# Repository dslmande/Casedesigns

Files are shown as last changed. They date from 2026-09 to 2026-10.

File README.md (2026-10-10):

# Case designs

Mechanical designs (front panels, rear panels, enclosures) for DIY synthesizer and
effects projects — parametric, generated from Python scripts, with ready-to-order
manufacturing files.

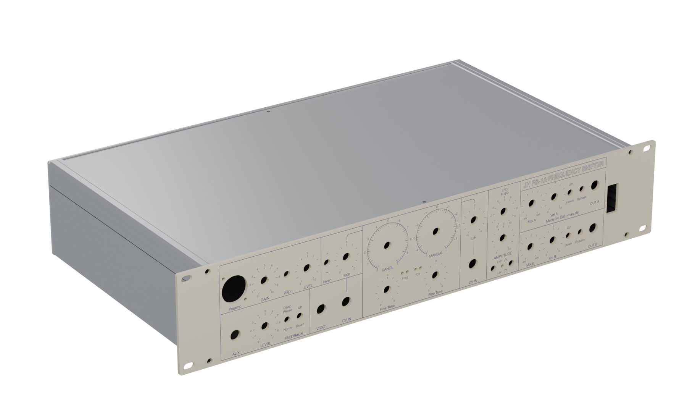
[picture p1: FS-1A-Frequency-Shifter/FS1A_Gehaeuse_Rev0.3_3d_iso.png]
FS-1A enclosure


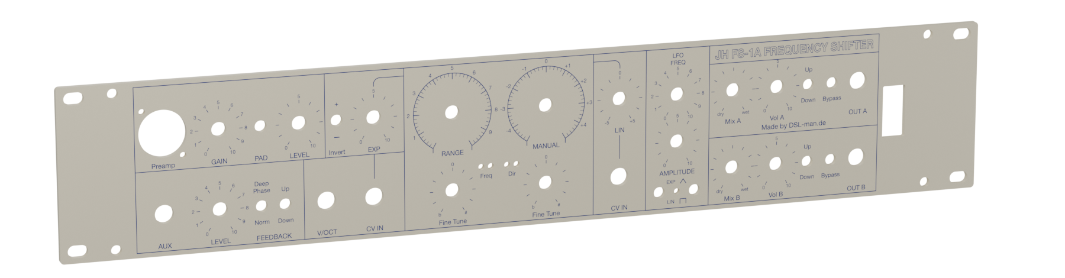
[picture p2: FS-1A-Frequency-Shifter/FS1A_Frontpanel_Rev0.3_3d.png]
FS-1A front panel


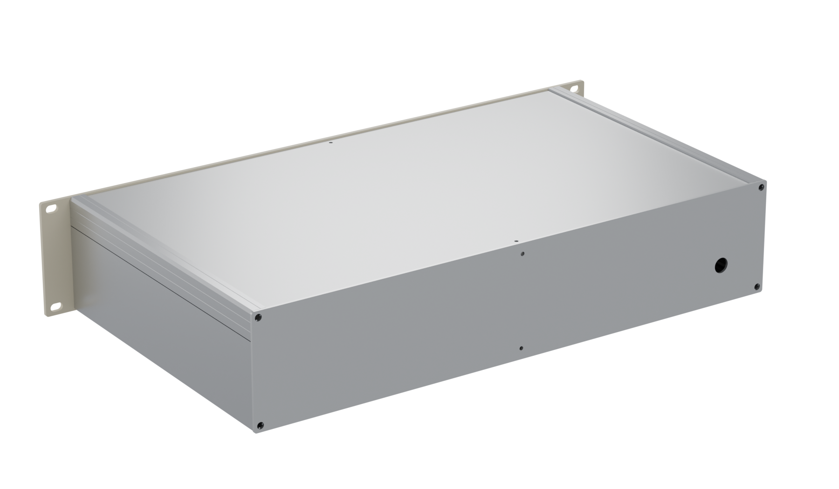
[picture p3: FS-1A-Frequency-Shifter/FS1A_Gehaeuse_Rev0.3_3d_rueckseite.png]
FS-1A rear


*FS-1A Frequency Shifter: 19" / 2 U enclosure, front panel with the full-surface
colour print, and the rear. Rendered from the STEP assembly these files produce —
the panel carries the actual print artwork, not a mock-up.*

**[Turn it around in your browser](https://dslmande.github.io/fs1a-case-3d/)** — an
interactive 3D view of the enclosure and the control PCBs.

| Design | Description |
|---|---|
| [FS-1A Frequency Shifter](FS-1A-Frequency-Shifter/) | 19" / 2 U front panel, rear panel and enclosure for Jürgen Haible's FS-1A frequency shifter |

Every design folder contains the generator scripts, the production files (Schaeffer
`.fpd`, DXF, print-ready PDF), a 3D assembly as STEP, and its own README.

## Control panel PCBs

For the FS-1A there is a set of control panel PCBs that carries the pots, switches,
jacks and LEDs behind the front panel, so the build needs no point-to-point wiring.
Three boards, one per block of the panel layout, wired to each other with a single
6-way link and to Haible's boards with the connectors he already uses.

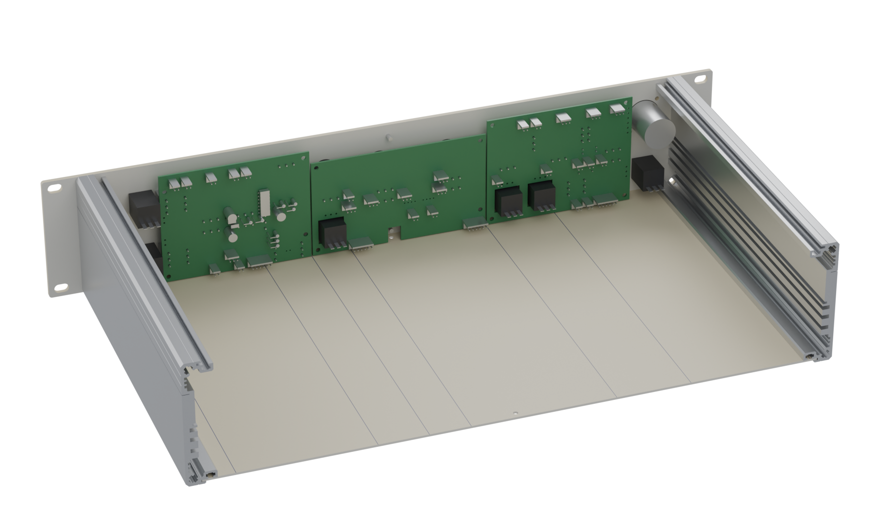
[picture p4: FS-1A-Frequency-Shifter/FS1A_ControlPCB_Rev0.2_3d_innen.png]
Control panel PCBs behind the front panel


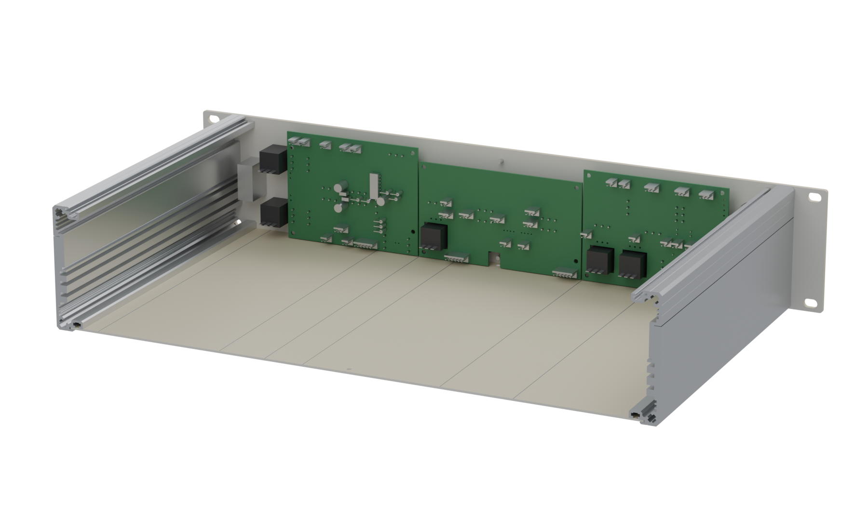
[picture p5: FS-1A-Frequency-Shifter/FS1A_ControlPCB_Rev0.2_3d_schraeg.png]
Control panel PCBs from the side


Those boards are not part of this repository — they are **available on request from
[diysynth.de](https://diysynth.de)**.

## License

© 2026 Dsl-man.de

Licensed under [Creative Commons Attribution-ShareAlike 4.0 International](LICENSE)
(CC BY-SA 4.0) — including the generator scripts. You may build, modify and redistribute
these designs, commercially too, as long as you credit the source and share your changes
under the same license.

Third-party data included for reference keeps its own origin: the side-rail cross-section
comes from Gie-Tec's published CAD file, `rowmans.jhf` is the public-domain Hershey font.

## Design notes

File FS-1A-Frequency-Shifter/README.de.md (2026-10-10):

# Frontpanel – Jürgen Haible Frequency Shifter FS-1A (19", 2 HE)

Gestaltung nach dem Vorbild des Van-Daal-Aufbaus (cremefarbene Blende,
dunkelblauer Druck, Funktionsblöcke mit Rahmenlinien, große RANGE/MANUAL-Knöpfe).

## Versionsstand

Alle erzeugten Dateien tragen den Stand im Namen, Schema
`FS1A_<Teil>_Rev<x.y>[_<Zusatz>].<ext>` – aktuell **Rev0.3**. Die Generatoren
(`fs1a_panel.py`, `fs1a_rueckwand.py`, `fs1a_gehaeuse.py`, `fs1a_step.py`) und die
Eingangsdaten (`gietec_122040_profil.dat`, `rowmans.jhf`) bleiben ohne Version, sie
sind das Werkzeug. Der Stand steht an einer Stelle: `REV` am Anfang von
`fs1a_panel.py`; die anderen Skripte übernehmen ihn von dort.

Jede Maß- oder Bauteiländerung an einem Teil ist ein neuer Stand: `REV` hochzählen,
alles neu erzeugen, die alten Dateien behalten oder verwerfen – so kommen bestellte
Platten und Daten nicht durcheinander.

> **Die Druckvariante speichert das Skript nicht.** „Weiß drucken“ und „Weiß
> unterdrucken“ gibt es nur im Eigenschaften-Dialog, eine vom Skript geschriebene
> Datei hätte sie immer auf Nein. Also: Skript laufen lassen, beide setzen, dann von
> Hand als `FS1A_Frontpanel_Rev0.3_druck.fpd` sichern.

## Dateien

| Datei | Inhalt |
|---|---|
| `fs1a_panel.py` | Generator (nur Python-Standardbibliothek): `/usr/bin/python3 fs1a_panel.py` schreibt alle Ausgabedateien neu |
| `FS1A_Frontpanel_Rev0.3_druck.fpd` | **FrontDesign, Farbdruck-Variante:** eloxiert natur + vollflächige Druckgrafik (Creme + Blau), Bohrungen als Bohrelemente |
| `FS1A_Frontpanel_Rev0.3_druck.pdf` | Die Druckgrafik: Vektor-PDF 1:1, 484,7 × 90,3 mm (1 mm Beschnitt rundum), ohne Bohrungen/Kontur |
| `FS1A_Frontpanel_Rev0.3_druck.fpjs` | FrontDesign-Skript, das die Druck-Variante erzeugt |
| `FS1A_Frontpanel_Rev0.3.fpd` | FrontDesign, Gravur-Variante: Text/Linien als native Elemente (gravieren oder „Gravuren drucken“) |
| `FS1A_Frontpanel_Rev0.3.fpjs` | FrontDesign-Skript für die Gravur-Variante |
| `FS1A_Frontpanel_Rev0.3.dxf` | DXF R12, Ebenen `KONTUR` / `AUSSCHNITTE` / `DRUCK`, Text als Pfade |
| `FS1A_Frontpanel_Rev0.3.svg` | 1:1 in mm mit Inkscape-Ebenen und Bauteil-Vorschau |
| `FS1A_Frontpanel_Rev0.3_druck.svg` | Quelle der Druckgrafik (nur Panelfarbe + Druck) |
| `FS1A_Frontpanel_Rev0.3_bohrungen.csv` | Bohrtabelle: Nr, Bauteil, x (von links), y (von oben), Ø, Bemerkung |
| `FS1A_Frontpanel_Rev0.3_vorschau.png` | Render mit Knöpfen, Buchsen, Schaltern |
| `fs1a_rueckwand.py` | Generator der Rückwand (nutzt `fs1a_panel.py` als Bibliothek) |
| `FS1A_Rueckwand_Rev0.3.fpd` | FrontDesign, Rückwand 437 × 88,1 × 2 mm, Alu eloxiert natur |
| `FS1A_Rueckwand_Rev0.3.svg` / `.dxf` / `.fpjs` / `_bohrungen.csv` / `_vorschau.png` | Rückwand in denselben Formaten |
| `rowmans.jhf` | Hershey-Strichschrift „Roman Simplex“ für den DXF-Text (gemeinfrei) |

Alle Maße und Positionen stehen als Konstanten am Anfang von `fs1a_panel.py`
(Blockgrenzen `X_*`, Reihenhöhen `Y_TOP/Y_BOT`, Bohrdurchmesser `DRILL`, Farben,
Schriftgrößen, `TITLE`, `BRAND`, FrontDesign-Einstellungen `FPD`, Beschnitt `BLEED`).
Die PDF-Erzeugung nutzt Google Chrome headless (`CHROME`-Pfad im Script).

## Farbdruck (UV-Digitaldruck) – `FS1A_Frontpanel_Rev0.3_druck.fpd`

So sieht die Platte aus wie das Vorbild. Regeln aus Schaeffers „Hinweise zur Erstellung
Ihrer Druckdaten“ (Druckdateien.pdf), die der Generator einhält:

- Vektor-PDF, Farben in sRGB (Creme `#F2E7C6`, Blau `#22307C`) – RAL wird nur angenähert.
- Die Druckgrafik läuft rundum ≥ 1 mm über die Plattenkante hinaus (sonst kann unbedruckter Rand sichtbar werden).
- Keine Bohrungen und keine Plattenkontur in der Druckdatei (würden mitgedruckt).
- Bedruckt wird nur Schaeffers eloxiertes Aluminium – daher Material `alu_elox` / natur,
  pulverbeschichtete Platten sind nicht bedruckbar.
- Weiß: standardmäßig wird Weiß nicht gedruckt. Für die deckende Creme-Fläche in den
  Platteneigenschaften (Strg-F) **„Weiß fluten“** (weiße Grundierung der ganzen Platte) einschalten;
  ohne Weiß schimmert das Aluminium durch und die Creme wird grau.

Das Skript erzeugt Bohrungen + `PrintGraphic` (Bezugspunkt unten links bei (−1,06, −1,11) mm,
Skalierung 100 %). Neu erzeugen: Bearbeiten → Skripte → PastePad →
`EvalFile("/…/FS1A_Frontpanel_Rev0.3_druck.fpjs");` → Start.

## Gravur-Variante – `FS1A_Frontpanel_Rev0.3.fpd`

Platte 482,6 × 88,1 × **3 mm**, Aluminium pulverbeschichtet Grauweiß RAL 9002 (Creme gibt es
nicht), Eckenradius 2 mm, 52 Bohrungen/Langlöcher, 125 Textgravuren (Helvetica Light
1-stroke, Titel Helvetica Medium outline), HPGL-Gravur mit Rahmen, Skalen und Bögen.
Gravurfarbe Nachtblau RAL 5022, Option „Gravuren drucken“ gesetzt. Für echte Gravur mit
Farbauslegung `FPD["printed"] = False` setzen.

## DXF (Alternative)

Datei → Importieren… → `FS1A_Frontpanel_Rev0.3.dxf`. Der Import-Assistent erkennt die größte
geschlossene Kontur als Plattenumriss, Kreise als Bohrungen und die Langlöcher als freie
Konturen. Ebene `DRUCK` enthält den Text als Pfade (Strichschrift). Auch für KiCad/Inkscape.

## Ebenen in der SVG (Inkscape-Ebenen)

| Ebene | Zweck |
|---|---|
| 0 Hintergrund | Panelfarbe – nur Vorschau |
| 1 Kontur | Außenkontur 482,6 × 88,1 mm, Ecken R 2 |
| 2 Ausschnitte | Bohrungen und Rack-Langlöcher mit Ist-Durchmesser |
| 3 Druck | Beschriftung, Rahmen, Skalen |
| 4 Bauteile | Knöpfe, Buchsen, Schalter, LEDs – nur Vorschau |
| 5 Bohrmaße | Durchmesser neben jeder Bohrung, standardmäßig aus |

`python3 fs1a_panel.py --no-preview` schreibt die SVG ohne Vorschau-Ebenen.

## Bohrungen (Standardwerte)

| Bauteil | Ø | Anmerkung |
|---|---|---|
| Potis (Alpha 16 mm) | 7,5 | Verdrehsicherung ggf. ergänzen |
| Klinke 6,35 mm | 9,5 | Neutrik NYS / Cliff |
| Neutrik Combo NCJ6FI-S (Lötversion) | 24,0 | + 2 × Ø 3,2 oben links / unten rechts, 20 × 23 mm versetzt (Neutrik-Zeichnung 3102ST1728). PCB-Version NCJ6FA-H bräuchte Ø 22 und 19,8 × 19,8 mm – Konstanten `COMBO_SCREW_DX/DY` |
| Mini-Kippschalter | 6,0 | M6-Gewindebuchse, 9 Stück |
| LED 3 mm | 3,2 | Freq/Dir ×4, LFO ×1 |
| Netzschalter | 12,3 × 27,2, R 1 | Marquardt 1555.3102 Wippschalter (Reichelt WIPPE 1555.3102), Snap-in, hochkant; Datenblatt 27,2 ±0,1 × 12,2 +0,2, Wandstärke 0,8–5 mm, Blende 30 × 15. Keine On/Off-Beschriftung |
| Schrauben M5 | 5,3 | 4 × Befestigung an den Seitenteilprofilen (x 27,8 / 454,8, y 4,9 / 83,2), **Zylinderkopf** |
| Rack-Langlöcher | 10 × 6,4 | Lochmitten 465,1 mm, ±38,1 mm von der Panelmitte |
| Gewindebolzen M3 | kein Loch | 2 × Einklebebolzen GU30, 6 mm, auf der **Rückseite** bei x 241,3 / y 8,35 und 79,75 |

Vor der Bestellung die Durchmesser mit den tatsächlich verwendeten Bauteilen abgleichen.

## Gehäuse

Blende wird an zwei **Gie-Tec Seitenteilprofilen 4** (Art. 122040) verschraubt – Seitenteil für
19-Zoll-Gehäuse 2 HE, 88,30 mm hoch, Anlagefläche 16 mm (hinten bis 20,5 mm), Schraubkanäle Ø 4,5
für M5, Kanalmitte je 5 mm von Ober-/Unterkante (Abstand **78,3 mm**) und 5 mm hinter der
Außenfläche.

Gehäuse-Außenbreite `BOX_WIDTH = 437` mm → Profile belegen hinter der Blende x 22,8–38,8 und
443,8–459,8. Kein Bauteilkörper darf dort hineinragen; im Generator stehen die Grenzen als
`X_PROFILE_IN_L` / `X_PROFILE_IN_R`. Deshalb:

- Preamp-Combo bei x 52 (Gehäuse Ø 23,4 → 1,5 mm Luft zum Profil)
- Ausgangsblock endet bei x 426, Wippschalter bei x 435 (Blende 427,5–442,5 → 1,3 mm Luft)
- keine Befestigungsschrauben in der Blendenmitte (dort gibt es keinen Gegenhalt)

`FS1A_Rev0.3_pruefung_gehaeusezonen.png` zeigt die Profilzonen rot über dem Layout.

## Befestigungsschrauben: Zylinderkopf, kein Senkkopf

Die Schraubkanäle liegen 5 mm von der Profilkante, die Blende ist 0,2 mm niedriger als das
Profil → **Lochmitte nur 4,9 mm von der Blendenkante**. Geprüft wurde:

| Variante | Ø Kopf / Senkung | Rand bis zur Blendenkante |
|---|---|---|
| Schaeffer-Senkung DIN 74A-M5 (3 mm Platte) | 10,94 | **−0,57 mm** – schneidet die Kante an |
| M5 Senkkopf DIN 7991 / ISO 10642 (Innensechskant) | 10,0 | **−0,10 mm** |
| M5 Senkkopf DIN 965 / ISO 7046 (Kreuzschlitz) | 9,2 | +0,30 mm – sehr dünne Kante |
| **M5 Zylinderkopf DIN 912 – gewählt** | **8,5** | **+0,65 mm** |

Die DIN-965-Senkung war probeweise eingebaut (Kegel Ø 9,2 / 90°, 2,15 mm tief) und
funktioniert in FrontDesign; 0,30 mm Restmaterial an der Blendenkante sind aber zu wenig.
Deshalb bleibt es bei der glatten Bohrung Ø 5,3 und Zylinderkopfschrauben.

Wieder einschalten: in `fs1a_panel.py` die Zeile `CSK_TYPE = None` durch die darüber
auskommentierte Zeile ersetzen – Bohrung, Senkung, CSV, Vorschau und STEP ziehen mit.

## Versteifung: Winkel zwischen Blende und Blechen

Damit sich die Blende nicht gegen die Bleche verwindet, sitzt oben und unten mittig je ein
**Gewindebolzen M3** auf der Rückseite der Frontplatte (FrontDesign-Element `Bolt`,
Typ GU30 = Einklebebolzen mit 3-mm-Gewinde, 6 mm lang). Darauf kommt ein Winkel
**Keystone 633**, dessen zweiter Schenkel ans Deckel- bzw. Bodenblech geschraubt wird.

Maße des Winkels (Messing vernickelt): Schenkel 9,5 × 9,5 mm, Breite 7,1 mm, Material
0,81 mm, beide Löcher Ø 3,7 mm, **Lochmitte je 5,5 mm von der Außenfläche des anderen
Schenkels**. Daraus folgt alles Weitere:

Hinten dasselbe, nur mit Schraube statt Bolzen: die Rückwand bekommt an der gleichen
Stelle zwei Durchgangslöcher, der Winkel wird von außen angeschraubt.

| Merkmal | Wert |
|---|---|
| Bolzen Frontplatte | x 241,3 (Mitte), y **8,35** und **79,75** von der Oberkante |
| Löcher Rückwand | Ø **3,2**, x 218,5 (Mitte), y **8,35** und **79,75** von der Oberkante |
| Löcher in Deckel und Boden | Ø **3,2**, mittig (208 mm von links), **5,5 mm von der Vorderkante** und **5,0 mm von der Hinterkante** |
| Abstand Bolzen-/Schraubenachse ↔ Blechfläche | 5,5 mm (= Maß D des Winkels) |
| Nächstes Bauteil | Fine-Tune-Poti, 14,4 mm entfernt – frei |

Warum hinten 5,0 statt 5,5 mm: Das Blech endet 0,5 mm vor der Profilstirnfläche, an der die
Rückwand anliegt.

Zusätzlich nötig: 2 × Mutter M3 (auf die Bolzen der Blende), 6 × Schraube M3 + Mutter
(2 × Winkel an die Rückwand, 4 × Winkel an Deckel und Boden).

## Rückwand – `FS1A_Rueckwand_Rev0.3.fpd`

437 × 88,1 × 2 mm (Gehäuse-Außenbreite, deckt die Stirnflächen der Seitenteilprofile ab),
Alu eloxiert natur, Eckenradius 2 mm, unbedruckt.

| Bohrung | Position | Ø |
|---|---|---|
| 4 × M5 in die Schraubkanäle | x 5 / 432, y 4,9 / 83,2 | 5,3 |
| Kabeldurchführung | x 40 (von links), y 58,1 (= 30 mm von unten) | 12,0 |
| 2 × Winkelschraube M3 | x 218,5 (Mitte), y 8,35 / 79,75 | 3,2 |

Erzeugen: `python3 fs1a_rueckwand.py`, dann in FrontDesign
`EvalFile("/…/FS1A_Rueckwand_Rev0.3.fpjs");`. Maße stehen oben in `fs1a_rueckwand.py`
(`HOLE_D`, `HOLE_X`, `HOLE_Y_FROM_BOTTOM`).

## Gehäuse – Seitenteile, Deckel, Boden

`python3 fs1a_gehaeuse.py` erzeugt die Gehäuseteile und gibt die Stückliste aus.
Gehäusetiefe `BOX_DEPTH = 250` mm (Profillänge), Außentiefe **255 mm** (Blende 3 mm + Rückwand 2 mm).

| Anz. | Teil | Maß / Datei |
|---|---|---|
| 2 | Seitenteilprofil | Gie-Tec 122040, Zuschnitt **250 mm** (Sonderlänge bestellbar) |
| 1 | Frontplatte | 482,6 × 88,1 × **3** – `FS1A_Frontpanel_Rev0.3.fpd` bzw. `_druck.fpd` |
| 1 | Rückwand | 437 × 88,1 × 2 – `FS1A_Rueckwand_Rev0.3.fpd` |
| 2 | Deckel / Boden | **416 × 249,5 × 1,5 mm Alu-Blech**, 2 Löcher Ø 3,2 – `FS1A_Deckel_Boden_Rev0.3.dxf` |
| 8 | Schraube M5 Zylinderkopf | gewindeformend in die Profilkanäle, 4 vorn + 4 hinten |
| 4 | Winkel Keystone 633 | oben/unten mittig, vorn an der Blende und hinten an der Rückwand |
| 2 | Mutter M3 | auf die Gewindebolzen der Blende |
| 6 | Schraube M3 + Mutter | 2 × Winkel an die Rückwand, 4 × Winkel an Deckel/Boden |

Blechmaße aus der Profilkontur (`gietec_122040_profil.dat`, aus Gie-Tecs `cad_122040.dxf`):
Blechnut 1,6 mm breit auf Höhe 1,4–3,0 bzw. 85,3–86,9 mm, Nutgrund 10 mm hinter der
Außenfläche → freie Weite zwischen den Nutgründen 417 mm, Blech 416 mm (je 2,5 mm Eingriff,
0,5 mm Spiel). Länge 249,5 mm = Profillänge − 0,5 mm.

**Deckel/Boden nicht bei Schaeffer:** 416 × 249,5 mm gibt es dort nicht in 1,5 mm
(im Frontplatten Designer geprüft: „Das größere Maß der Frontplatte ist zu groß oder die
Frontplatte ist zu dünn"). 2 mm wäre lieferbar, passt aber nicht in die 1,6-mm-Nut.
Also Blechzuschnitt (DXF) beim Blechner bestellen.

`FS1A_Gehaeuse_Rev0.3_schnitt.svg/.png` zeigt den Querschnitt mit beiden Profilen, Blechen,
Schraubkanälen und Frontplatte; `FS1A_Deckel_Boden_Rev0.3_zeichnung.svg/.png` ist die bemaßte
Blechzeichnung.

## 3D-Baugruppe – `FS1A_Gehaeuse_Rev0.3.step`

`fs1a_step.py` baut alle sechs Teile in FreeCAD (headless) aus denselben Quellen wie die
Fertigungsdateien und schreibt eine STEP-Datei (AP214) mit benannten Produkten:

```bash
/Applications/FreeCAD.app/Contents/Resources/bin/freecadcmd fs1a_step.py
```

| Teil | Maß (mm) | Volumen |
|---|---|---|
| Frontplatte | 482,6 × 2 × 88,1 | 79,98 cm³ |
| Rückwand | 437 × 2 × 88,1 | 76,59 cm³ |
| Seitenteil links / rechts | 20,5 × 250 × 88,3 | je 150,86 cm³ |
| Deckel / Boden | 416 × 249,5 × 1,5 | je 155,69 cm³ |

Baugruppe 482,6 × 254 × 88,3 mm, zusammen 769,7 cm³ Aluminium ≈ 2,1 kg.

Koordinaten: X = Breite (0 = linke Kante der Frontplatte), Y = Tiefe (0 = Rückseite der
Frontplatte, +Y nach hinten), Z = Höhe (0 = Unterkante der Frontplatte). Die Seitenteile
stehen 0,1 mm über und unter der Blende (Profil 88,3 vs. Blende 88,1).

Die Profilkontur wird entlang y = 0 geschlossen – die drei M3-Nuten an der vorderen
Anlagefläche fehlen deshalb im Modell; alles andere entspricht der Gie-Tec-Kontur.
Ansichten der Baugruppe erzeugt `fs1a_blender.py`
(`FS1A_Gehaeuse_Rev0.3_3d_iso.png`, `_3d_rueckseite.png`, `FS1A_Frontpanel_Rev0.3_3d.png`);
die alten FreeCAD-Kontrollansichten sind seit 08.10.2026 raus.

## Koordinaten

SVG, DXF-Rücklesung und CSV: x von links, y von oben. FrontDesign und DXF-Datei:
y von unten (Ursprung unten links) – der Generator rechnet um.

## Bedienelemente (von links nach rechts)

Preamp (Combo, GAIN, PAD, LEVEL) · AUX-Eingang mit LEVEL, FEEDBACK (Deep Phase/Norm, Up/Down) ·
Invert, EXP-Abschwächer · V/OCT, CV IN · RANGE, MANUAL, 2 × Fine Tune, Freq/Dir-LEDs ·
LIN-Abschwächer, CV IN · LFO (FREQ, AMPLITUDE, EXP/LIN, Dreieck/Rechteck) ·
Out A / Out B (Mix dry/wet, Vol, Up/Down, Bypass, OUT) · Netzschalter.

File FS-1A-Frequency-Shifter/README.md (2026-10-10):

# Jürgen Haible FS-1A Frequency Shifter — 19" / 2 U case

Complete mechanical design for a rack-mount build of Jürgen Haible's **FS-1A frequency
shifter**: front panel, rear panel, side rails, top and bottom covers, plus a 3D assembly.

Everything is generated by Python scripts from one shared geometry model, so a changed
dimension propagates to *all* outputs — SVG, DXF, Schaeffer FrontDesign `.fpd`, the
print-ready PDF, the drill schedule and the STEP assembly.

> **The colour print variant is not saved by the script.** *Print white* and
> *Underprint white* exist only in FrontDesign's properties dialog, so a script-written
> file would always have them off. Run the script, set both, then save manually as
> `FS1A_Frontpanel_Rev0.3_druck.fpd`.

Enclosure

Front panel

**[Interactive 3D viewer](https://dslmande.github.io/fs1a-case-3d/)** — rotate, zoom, switch parts on and off, make the enclosure see-through, move a section through it. Source: [dslmande/fs1a-case-3d](https://github.com/dslmande/fs1a-case-3d).

The panel layout follows the well-known Van Daal Electronics build of the FS-1A (cream
panel, dark blue legend, framed function blocks, two large RANGE / MANUAL dials). Circuit
design: Jürgen Haible. This repository contains mechanical data only — no schematics, no
PCB files.

---

## Control panel PCBs

A set of control panel PCBs for this panel — pots, switches, jacks and LEDs on the
board, no point-to-point wiring — is **available on request from
[diysynth.de](https://diysynth.de)**. Those boards are not part of this repository.

Three boards, split along the frame lines of the panel layout (107.5 × 81, 126 × 71.2
and 105 × 81 mm), mounted on M3 spacers behind the panel. They carry the 15 pots, 10
toggle switches, 6 jacks, the combo socket and the LEDs, link to each other with one
6-way cable and plug into Haible's boards with his own connector pinout.

Control panel PCBs behind the front panel

Control panel PCBs from the side

## Bill of materials

| Qty | Part | Size / spec | File |
|---|---|---|---|
| 1 | Front panel | 482.6 × 88.1 × **3 mm**, corner R2 | `FS1A_Frontpanel_Rev0.3.fpd` or `FS1A_Frontpanel_Rev0.3_druck.fpd` |
| 1 | Rear panel | 437 × 88.1 × 2 mm, corner R2 | `FS1A_Rueckwand_Rev0.3.fpd` |
| 2 | Side rail | Gie-Tec *Seitenteilprofil 4* (art. 122040), cut to **250 mm** | purchased part |
| 2 | Top / bottom cover | 416 × 249.5 × **1.5 mm** aluminium sheet, two Ø3.2 holes | `FS1A_Deckel_Boden_Rev0.3.dxf` |
| 8 | Screw M5 cheese head | thread-forming, into the rail channels (4 front, 4 rear) | — |
| 4 | Angle bracket | Keystone **633**, front and rear, to top and bottom cover | — |
| 2 | Nut M3 | onto the front panel studs | — |
| 6 | Screw M3 + nut | 2 brackets to the rear panel, 4 to the covers | — |

Overall size **482.6 × 88.1 × 255 mm** (panel), body 437 mm wide, 250 mm deep.
Aluminium volume 809 cm³ ≈ **2.2 kg**.

---

## Front panel

482.6 × 88.1 mm, **3 mm** aluminium, **48 cutouts**, 123 legend items. Controls left to right:

* **Preamp** — Neutrik combo XLR/jack input, GAIN, PAD, LEVEL, signal + clip LED
* **AUX** — jack input, LEVEL, FEEDBACK (Deep Phase / Norm, Up / Down)
* **Invert**, **EXP** attenuator, **V/OCT** and **CV IN** jacks
* **RANGE** and **MANUAL** — 19 mm dials with 300° scales and fine graduation, 2 × Fine Tune, Freq / Dir LEDs
* **LIN** attenuator with **CV IN**
* **LFO** — FREQ, AMPLITUDE, EXP/LIN and triangle/square switches, LED
* **Out A / Out B** — Mix (dry…wet), Vol, Up/Down, Bypass, output jack each
* Illuminated **rocker power switch** at the right-hand edge

### Two variants

| File | Process |
|---|---|
| `FS1A_Frontpanel_Rev0.3.fpd` | Legend as native FrontDesign text and HPGL engravings — engrave and fill, or switch the whole panel to printing |
| `FS1A_Frontpanel_Rev0.3_druck.fpd` | Anodised aluminium plus a **full-surface UV colour print** (cream + blue), holes as drill elements — this is the one that looks like the reference build |

The print variant needs **"white flood"** enabled in *Panel properties* (Schaeffer prints
white only on request; without it the aluminium shows through and the cream turns grey).
The print artwork `FS1A_Frontpanel_Rev0.3_druck.pdf` is vector, sRGB, 1 mm bleed all round, and
contains no holes or panel outline — as required by Schaeffer's print-data guide.

### Hole schedule

| Item | Ø / size (mm) | Notes |
|---|---|---|
| Potentiometers | 7.5 | Alpha 16 mm, M7 bushing |
| 6.35 mm jacks | 9.5 | Neutrik NYS / Cliff |
| Neutrik combo **NCJ6FI-S** | 24.0 | plus 2 × Ø3.2, offset 20 × 23 mm (top left / bottom right), Neutrik drawing 3102ST1728 |
| Toggle switches (10 ×) | 6.0 | M6 bushing |
| LEDs (7 ×) | 3.2 | 3 mm, no bezel |
| Power rocker | 12.3 × 27.2, R1 | Marquardt 1555.3102, snap-in, mounted upright; datasheet cut-out 27.2 ±0.1 × 12.2 +0.2, panel 0.8–5 mm |
| M5 fixing screws | 5.3 | x 27.8 / 454.8, y 4.9 / 83.2 — **cheese head** |
| Rack slots | 10 × 6.4 | 465.1 mm pitch, ±38.1 mm from panel centre |
| M3 studs | no hole | 2 × glued-in stud GU30, 6 mm, on the **rear face** at x 241.3, y 8.35 and 79.75 |

Full list with coordinates: `FS1A_Frontpanel_Rev0.3_bohrungen.csv`
(columns: no., part, x from left, y from top, Ø, note).

---

## Fixing screws: cheese head, not countersunk

The rail screw channels sit 5 mm from the rail edge and the panel is 0.2 mm shorter than
the rail, so the hole centres are only **4.9 mm from the panel edge**. What was evaluated:

| Option | Ø head / countersink | Material left to the panel edge |
|---|---|---|
| Schaeffer countersink DIN 74A-M5 (3 mm panel) | 10.94 | **−0.57 mm** — cuts into the edge |
| M5 countersunk DIN 7991 / ISO 10642 (hex socket) | 10.0 | **−0.10 mm** |
| M5 countersunk DIN 965 / ISO 7046 (cross recess) | 9.2 | +0.30 mm — edge far too thin |
| **M5 cheese head DIN 912 — chosen** | **8.5** | **+0.65 mm** |

A DIN 965 countersink (cone Ø9.2 at 90°, 2.15 mm deep) was built and works in Front Panel
Designer, but 0.30 mm of remaining material at the panel edge is not enough. The panel
therefore keeps a plain Ø5.3 hole and cheese head screws.

To switch it back on, replace `CSK_TYPE = None` in `fs1a_panel.py` with the commented line
above it — hole, countersink, drill schedule, preview and STEP all follow.

## Stiffening brackets

To stop the panel twisting against the covers, an **M3 stud** sits on the rear face of the
front panel, top and bottom centre (FrontDesign `Bolt`, type GU30 = glued-in stud with
3 mm thread, 6 mm long). A **Keystone 633** angle bracket goes onto the stud, its other
leg is screwed to the top or bottom cover.

Bracket data (nickel-plated brass): legs 9.5 × 9.5 mm, width 7.1 mm, material 0.81 mm,
both holes Ø3.7 mm, **hole centre 5.5 mm from the outer face of the other leg**. Everything
else follows from that:

The rear does the same with a screw instead of a stud: the rear panel has two clearance
holes at the same height, and the bracket is bolted on from outside.

| Feature | Value |
|---|---|
| Stud on the front panel | x 241.3 (centre), y **8.35** and **79.75** from the top edge |
| Holes in the rear panel | Ø **3.2**, x 218.5 (centre), y **8.35** and **79.75** from the top edge |
| Holes in top and bottom cover | Ø **3.2**, centred (208 mm from the left edge), **5.5 mm from the front edge** and **5.0 mm from the rear edge** |
| Stud / screw axis to sheet face | 5.5 mm (= bracket dimension D) |
| Nearest component | Fine Tune pot, 14.4 mm away — clear |

The rear hole is 5.0 instead of 5.5 mm because the cover ends 0.5 mm short of the rail
face the rear panel sits against.

Hardware: 2 × nut M3 (onto the panel studs), 6 × screw M3 + nut (2 brackets to the rear
panel, 4 brackets to the covers).

## Rear panel

437 × 88.1 × 2 mm, natural anodised, unprinted. One Ø12 mm cable gland hole at
x = 40 mm from the left, 30 mm from the bottom, the four M5 holes into the rail channels
(x 5 / 432, y 4.9 / 83.2) and two Ø3.2 holes for the stiffening brackets
(x 218.5, y 8.35 / 79.75).

---

## Enclosure

The two side rails are **Gie-Tec Seitenteilprofil 4** (art. 122040, "side rail for 19"
enclosures, 2 U"), 88.30 mm tall, 20.50 mm deep, front face 16 mm. Their dimensions were
taken from the manufacturer's own CAD file; the extracted cross-section is stored as
`gietec_122040_profil.dat` and drives both the 2D section drawing and the 3D model.

* **Screw channels** Ø4.5 for M5, 5 mm from top and bottom edge (**78.3 mm apart**) and
  5 mm behind the outer face → the panel screws sit at x 27.8 / 454.8 mm.
* **Sheet grooves** 1.6 mm wide at 1.4–3.0 mm and 85.3–86.9 mm panel height, groove
  bottom 10 mm behind the outer face, 3 mm deep.
* Clear width between the groove bottoms 417 mm → cover sheets **416 mm** wide
  (2.5 mm engagement per side, 0.5 mm play), 249.5 mm long (0.5 mm shorter than the rails).

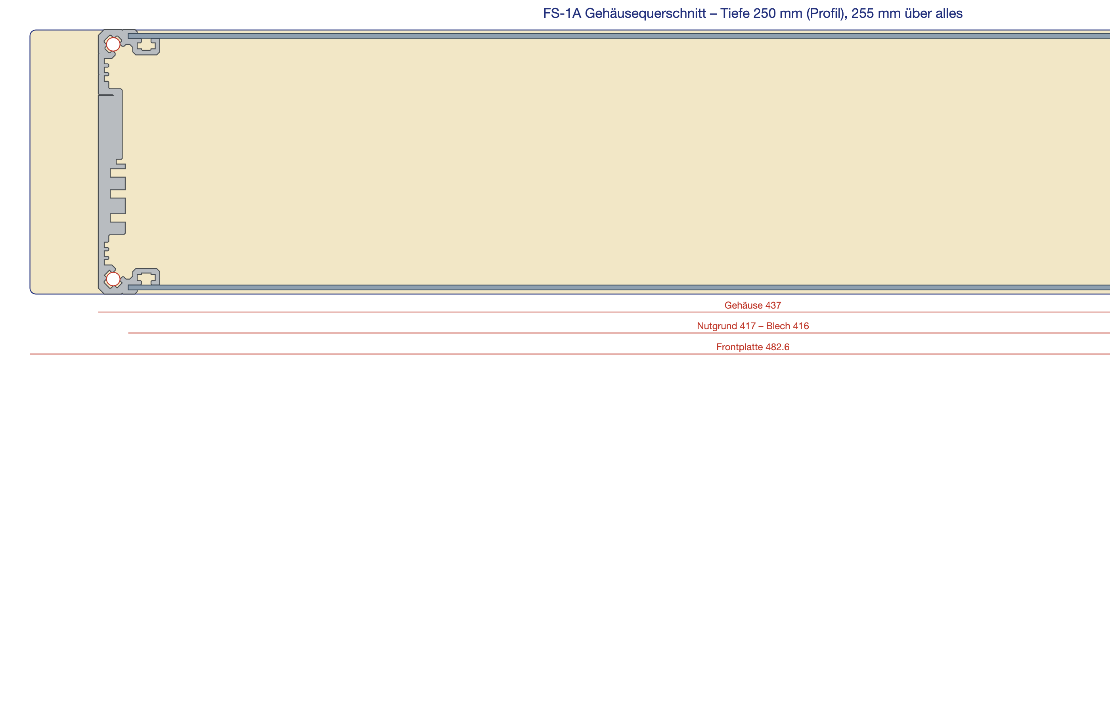
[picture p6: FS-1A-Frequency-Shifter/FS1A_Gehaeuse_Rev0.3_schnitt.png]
Cross section


Because the rails sit behind the panel (x 22.8–38.8 and 443.8–459.8 mm), no component
body may reach into those zones — the generator keeps them clear, and
`FS1A_Rev0.3_pruefung_gehaeusezonen.png` shows the zones overlaid on the layout.

> **Covers cannot be ordered from Schaeffer.** 416 × 249.5 mm is not available in 1.5 mm
> (their designer rejects it: *"the larger dimension is too big or the panel is too
> thin"*). 2 mm would be available but does not fit the 1.6 mm groove. Order the two
> covers as a plain sheet-metal cut from `FS1A_Deckel_Boden_Rev0.3.dxf`.

---

## 3D assembly

`FS1A_Gehaeuse_Rev0.3.step` — STEP AP214, eight named solids, built with FreeCAD from the same
geometry model:

| Solid | Size (mm) | Volume |
|---|---|---|
| Frontplatte (front panel) | 482.6 × 3 × 88.1 | 119.97 cm³ |
| Rueckwand (rear panel) | 437 × 2 × 88.1 | 76.59 cm³ |
| Seitenteil links / rechts (side rails) | 20.5 × 250 × 88.3 | 150.86 cm³ each |
| Deckel / Boden (top / bottom cover) | 416 × 249.5 × 1.5 | 155.68 cm³ each |
| Gewindebolzen oben / unten (studs) | Ø3 × 6 | 0.04 cm³ each |

Origin: X = width from the left panel edge, Y = depth from the back of the front panel
(+Y rearwards), Z = height from the bottom panel edge. The rails protrude 0.1 mm above
and below the panel (88.3 vs 88.1 mm).

Assembly

Rendered with Blender from the STEP above: `fs1a_blender.py` tessellates the
assembly with FreeCAD, puts the print artwork on the panel as a texture and
writes the three views. Run it with
`blender -b -P fs1a_blender.py`.

---

## Files

### Revision in every file name

Generated files carry the revision in their name, `FS1A_<part>_Rev<x.y>[_<suffix>].<ext>` —
currently **Rev0.3**. The generator scripts and the input data stay unversioned; they are the
tool. The revision lives in one place, `REV` at the top of `fs1a_panel.py`, and the other
scripts take it from there. Any change to a part's dimensions or hardware is a new revision:
bump `REV` and regenerate, so ordered panels and data files can never drift apart.

Scripts and their outputs (file names are German; this table maps them):

| File | What it is |
|---|---|
| `fs1a_panel.py` | Front panel generator — all dimensions, hole diameters, colours and fonts are constants at the top |
| `fs1a_rueckwand.py` | Rear panel generator (imports `fs1a_panel` as a library) |
| `fs1a_gehaeuse.py` | Enclosure: covers, cross-section drawing, bill of materials |
| `fs1a_step.py` | FreeCAD script that builds the STEP assembly |
| `FS1A_Frontpanel_Rev0.3.svg` / `.dxf` / `.fpd` / `.fpjs` | Front panel, engraved variant |
| `FS1A_Frontpanel_Rev0.3_druck.*` | Front panel, colour-print variant (`.pdf` = print artwork) |
| `FS1A_Frontpanel_Rev0.3_bohrungen.csv` | Drill schedule (Bohrungen = holes) |
| `FS1A_Rueckwand_Rev0.3.*` | Rear panel in the same formats |
| `FS1A_Deckel_Boden_Rev0.3.dxf` / `_zeichnung.svg` | Covers (Deckel = lid, Boden = bottom): cutting outline and dimensioned drawing |
| `FS1A_Gehaeuse_Rev0.3.step` | 3D assembly |
| `gietec_122040_profil.dat` | Side-rail cross-section, extracted from Gie-Tec's published CAD file |
| `rowmans.jhf` | Hershey "Roman Simplex" stroke font, used for text-as-paths in the DXF (public domain) |
| `README.de.md` | Full German documentation (more detail than this summary) |

### Regenerating

```bash
python3 fs1a_panel.py        # front panel: SVG, DXF, FPJS, CSV, print SVG + PDF
python3 fs1a_rueckwand.py    # rear panel
python3 fs1a_gehaeuse.py     # covers, cross section, BOM
/Applications/FreeCAD.app/Contents/Resources/bin/freecadcmd fs1a_step.py   # STEP
```

Only the Python standard library is required. The print PDF is rendered with headless
Google Chrome (path in `fs1a_panel.py`); the STEP needs FreeCAD 1.0.

The `.fpd` files are produced by running the generated `.fpjs` inside Schaeffer
FrontDesign: *Edit → Scripts → PastePad →* `EvalFile("/path/to/FS1A_Frontpanel_Rev0.3.fpjs");`
→ *Start*. Note that the white-print options are dialog-only and must be set by hand
after regenerating the print variant.

---

## Before you order

* Check every hole diameter against the parts you actually bought — the values are
  defaults for the components listed above.
* The combo jack is the **solder version NCJ6FI-S** (Ø24, screws 20 × 23 mm). The PCB
  version NCJ6FA-H needs Ø22 and 19.8 × 19.8 mm — constants `COMBO_SCREW_DX/DY`.
* Toggle holes are 6.0 mm; 1/4" bushings need 6.35 mm.
* Convert the text to paths before sending the SVG anywhere (the DXF already contains
  stroke-font outlines).
* Mains wiring: the illuminated rocker carries line voltage right next to the output
  jacks — use fully insulated 6.3 mm receptacles.

## Known simplifications

* The rail cross-section is closed along the front mounting face in the 3D model, so the
  three M3 slots on that face are missing. Everything else matches the manufacturer's
  contour.
* The enclosure depth of 250 mm is the **rail length**; with front and rear panel the
  outside depth is 254 mm. Change `BOX_DEPTH` in `fs1a_gehaeuse.py` if you want the
  other convention.

## License

© 2026 Dsl-man.de — [CC BY-SA 4.0](../LICENSE). Build it, change it, sell it; credit the
source and pass your changes on under the same license.

## Credits

* FS-1A circuit design: **Jürgen Haible** († 2011)
* Panel layout inspired by the **Van Daal Electronics** FS-1A build
* Side-rail geometry: **Gie-Tec GmbH**, from their published CAD data for article 122040
* Rocker switch data: **Marquardt** 1555.3102 datasheet · combo jack: **Neutrik** NCJ6FI-S

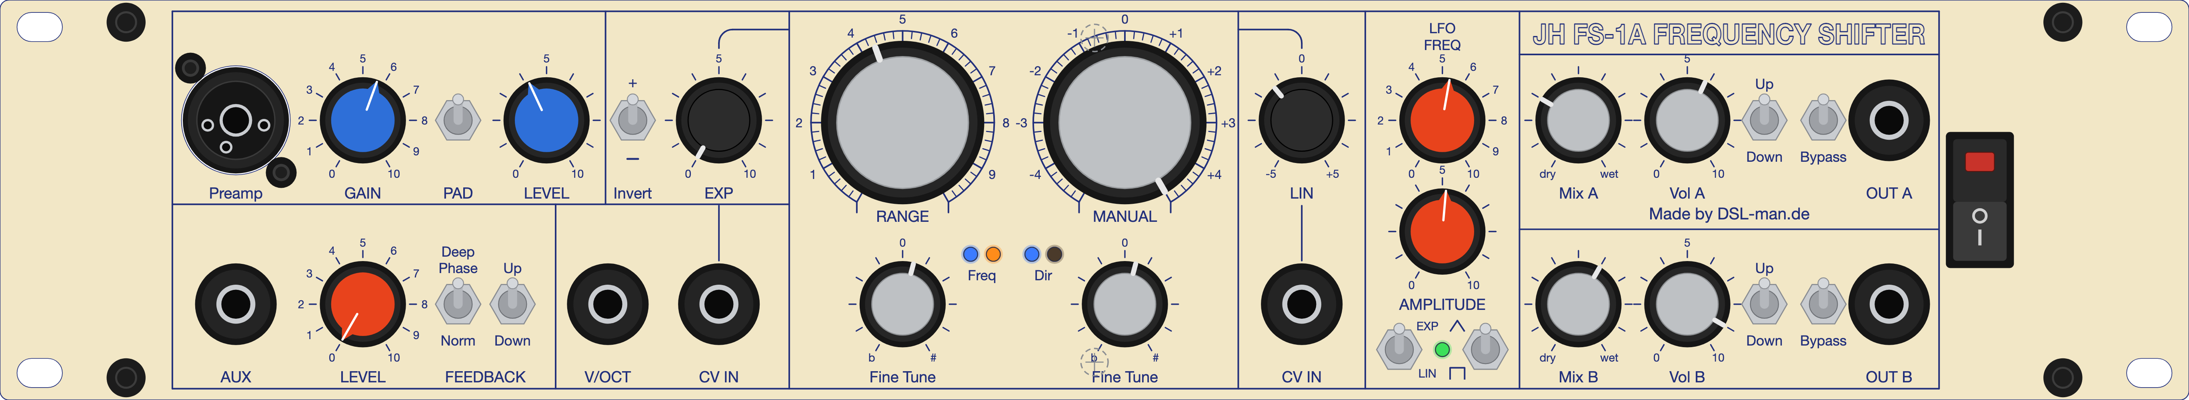
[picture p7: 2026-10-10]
FS-1A-Frequency-Shifter/FS1A_Frontpanel_Rev0.3_vorschau.png

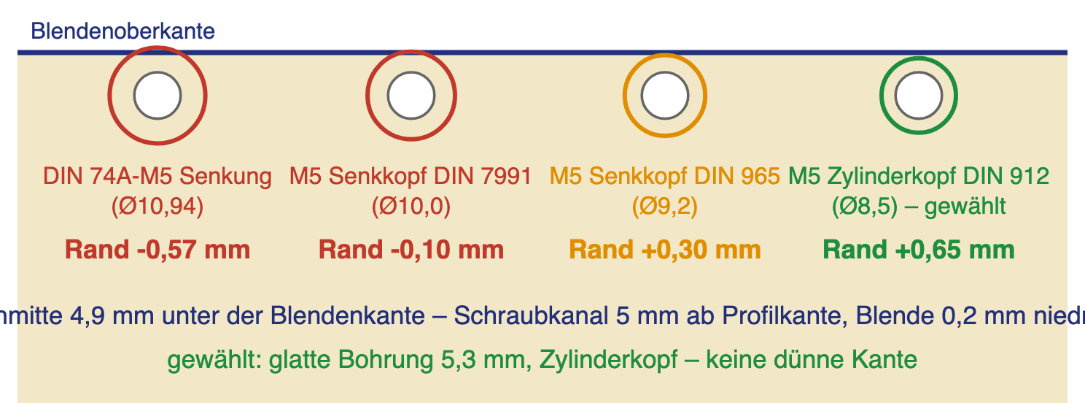
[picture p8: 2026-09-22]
FS-1A-Frequency-Shifter/FS1A_Rev0.3_pruefung_senkung.png

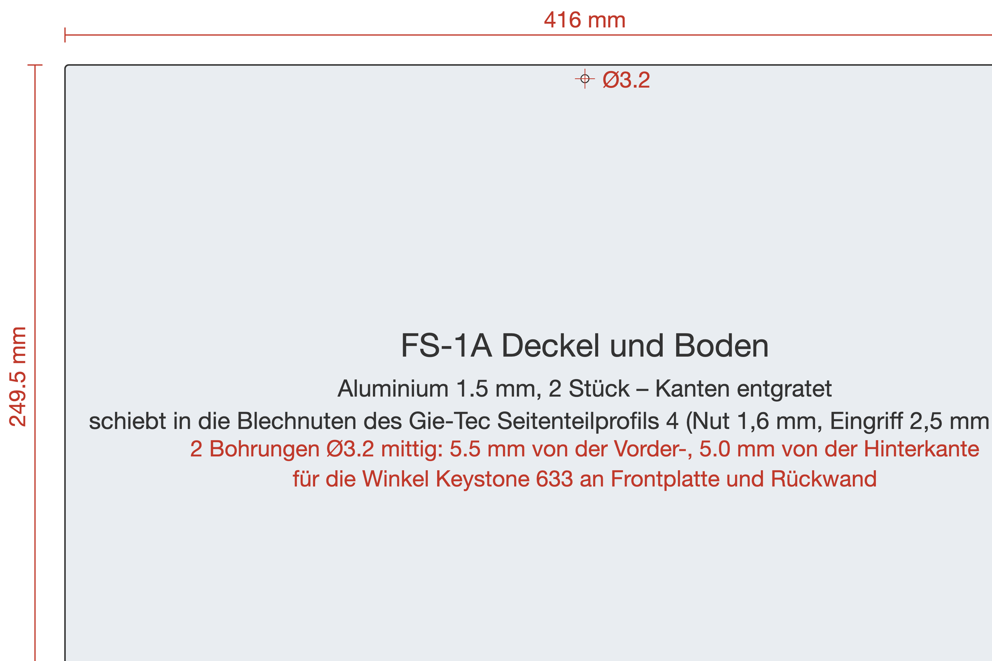
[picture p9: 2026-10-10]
FS-1A-Frequency-Shifter/FS1A_Deckel_Boden_Rev0.3_zeichnung.png

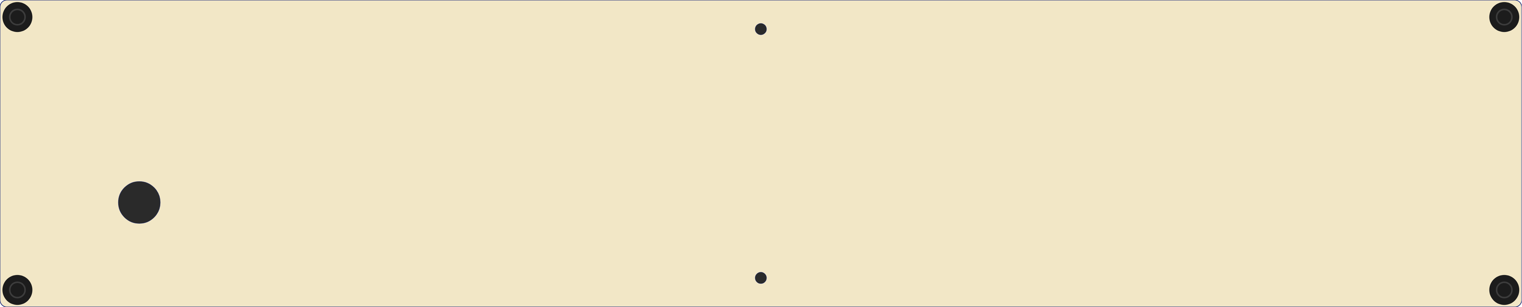
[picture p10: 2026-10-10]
FS-1A-Frequency-Shifter/FS1A_Rueckwand_Rev0.3_vorschau.png

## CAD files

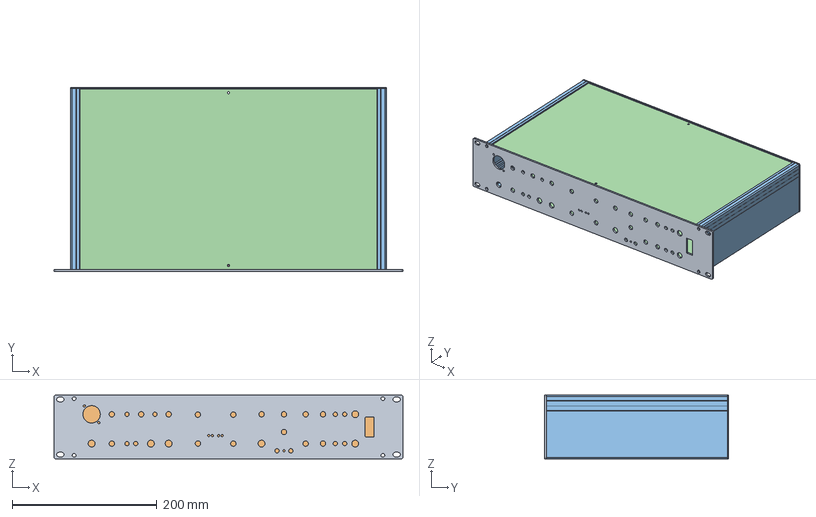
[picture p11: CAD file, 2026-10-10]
FS-1A-Frequency-Shifter/FS1A_Gehaeuse_Rev0.3.step
482.6 x 255.0 x 88.3 mm
Frontplatte
Rueckwand
Seitenteil links
Seitenteil rechts
Deckel
Boden
Gewindebolzen oben
Gewindebolzen unten

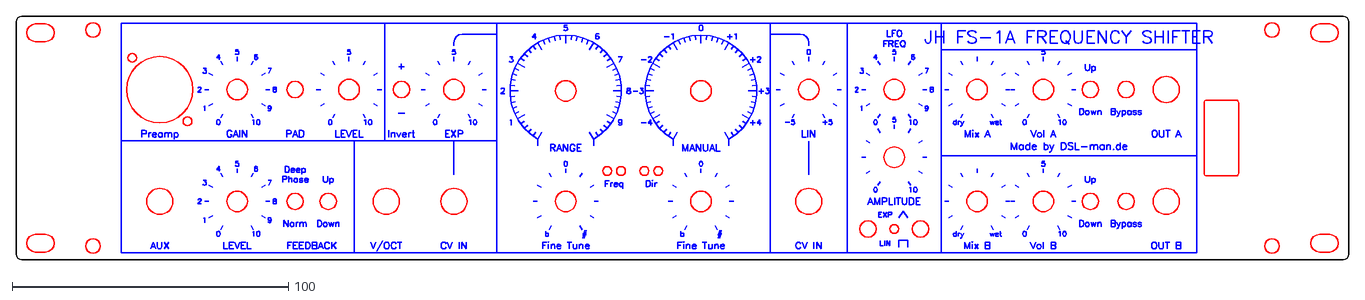
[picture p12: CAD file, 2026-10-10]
FS-1A-Frequency-Shifter/FS1A_Frontpanel_Rev0.3.dxf
482.6 x 88.1

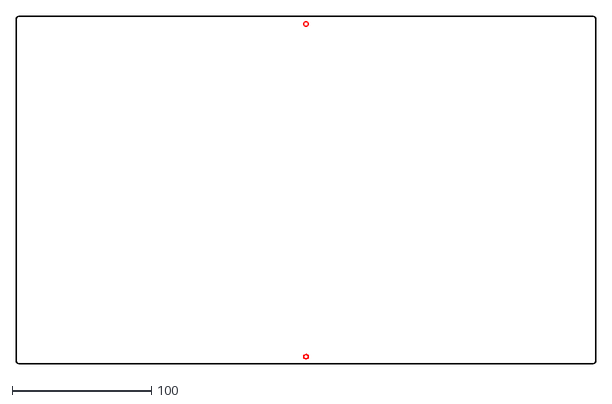
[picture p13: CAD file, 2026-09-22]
FS-1A-Frequency-Shifter/FS1A_Deckel_Boden_Rev0.3.dxf
416.0 x 249.5

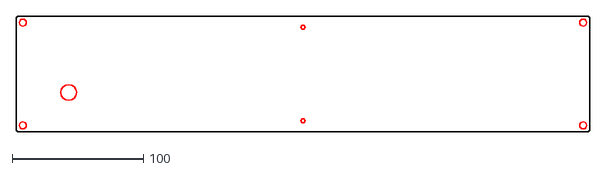
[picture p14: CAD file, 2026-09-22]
FS-1A-Frequency-Shifter/FS1A_Rueckwand_Rev0.3.dxf
437.0 x 88.1

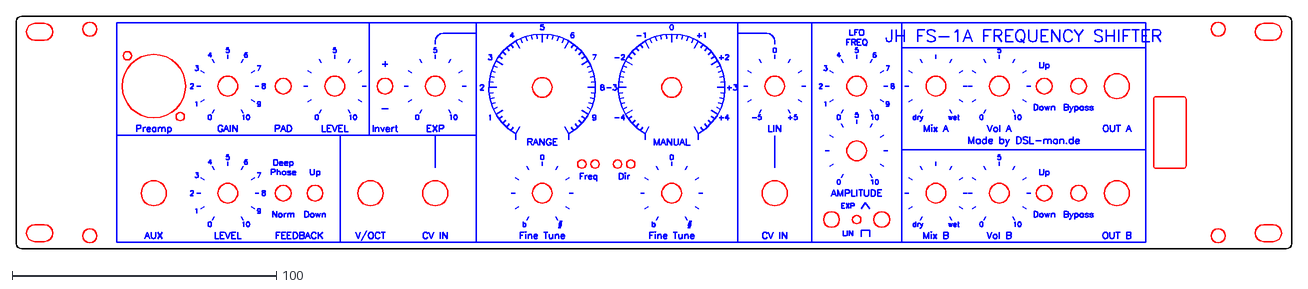
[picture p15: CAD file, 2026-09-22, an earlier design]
FS-1A-Frequency-Shifter/FS1A_Frontpanel_Rev0.1.dxf
482.6 x 88.1

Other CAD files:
FS-1A-Frequency-Shifter/FS1A_Gehaeuse_Rev0.2.step
FS-1A-Frequency-Shifter/FS1A_Gehaeuse_Rev0.1.step
FS-1A-Frequency-Shifter/fs1a_gehaeuse.step

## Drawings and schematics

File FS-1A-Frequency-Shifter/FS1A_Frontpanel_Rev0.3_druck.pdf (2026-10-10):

## + Inve

J

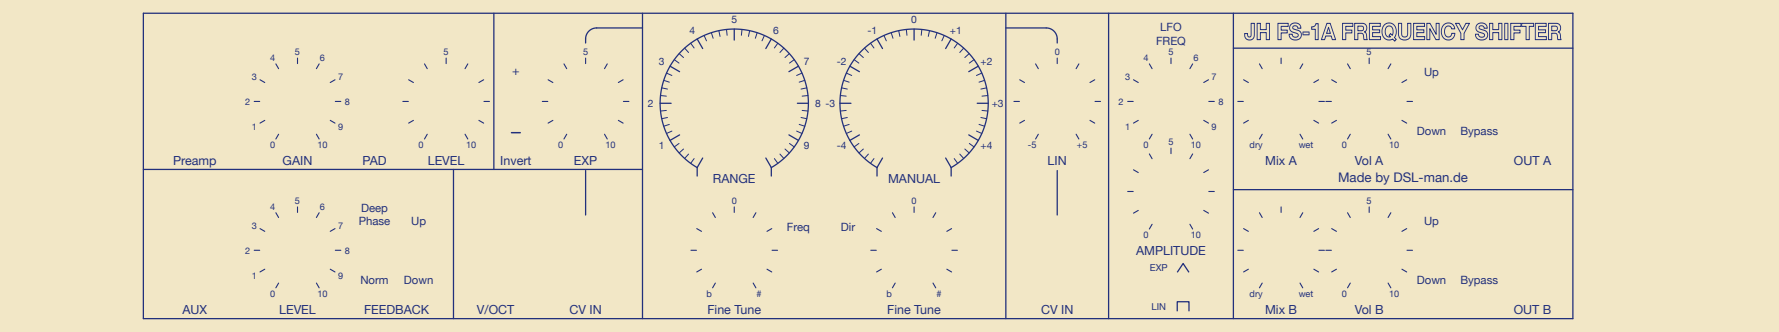
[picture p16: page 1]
AIN; Dir; LITU; LIN; Mix; Vol

LIN CV IN

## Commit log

2026-09-22 Add FS-1A frequency shifter case design
    Complete mechanical design for a 19" / 2 U build of Jürgen Haible's FS-1A
    frequency shifter, generated from one shared geometry model:
    - front panel 482.6 x 88.1 x 2 mm, 48 cutouts, in two variants (engraved
    legend / full-surface UV colour print on anodised aluminium)
    - rear panel 437 x 88.1 x 2 mm with a 12 mm cable gland hole
    - enclosure around two Gie-Tec 122040 side rails, 250 mm deep, with
    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
    [fs1a_deckel_boden.dxf, fs1a_frontpanel.dxf, fs1a_frontpanel_bohrungen.csv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]
2026-09-22 Set copyright holder to Dsl-man.de
2026-09-22 Add M3 studs and bracket holes for panel-to-cover stiffening
    Two glued-in M3 studs (FrontDesign Bolt GU30, 6 mm) on the rear face of the
    front panel, top and bottom centre, plus a matching 3.1 mm hole in each
    cover sheet. A Keystone 633 angle bracket ties the panel to the covers so
    the front cannot twist.
    Positions follow the bracket geometry (legs 9.5 x 9.5, hole centre 5.5 mm
    from the other leg's outer face): studs at x 241.3, y 8.35 / 79.75; cover
    holes centred, 5.5 mm from the front edge. Nearest component is 14.4 mm
    away. Studs and cover holes are in the STEP assembly as well.
    [fs1a_deckel_boden.dxf, fs1a_deckel_boden_bohrungen.csv, fs1a_frontpanel_bohrungen.csv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]
2026-09-22 Add bracket fixing holes to the rear panel
    The rear panel now carries two M3 clearance holes (Ø3.2, x 218.5,
    y 8.35 / 79.75) at the same height as the front panel studs, and each
    cover gets a second Ø3.1 hole 5.0 mm from its rear edge — the cover ends
    0.5 mm short of the rail face, so the offset differs from the 5.5 mm at
    the front. Four Keystone 633 brackets now tie both panels to the covers.
    [fs1a_deckel_boden.dxf, fs1a_deckel_boden_bohrungen.csv, fs1a_gehaeuse.step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]
2026-09-22 Use 3.2 mm clearance holes for M3 throughout
    The cover sheets had 3.1 mm; all M3 clearance holes are now 3.2 mm, same
    as the rear panel.
    [fs1a_deckel_boden.dxf, fs1a_deckel_boden_bohrungen.csv, fs1a_gehaeuse.step]
2026-09-22 Change panel brand line to 'Made by DSL-man.de'
    [fs1a_frontpanel.dxf, fs1a_gehaeuse.step]
2026-09-22 Front panel is 3 mm; document why the fixing screws stay cheese head
    Panel thickness corrected to 3 mm (overall depth now 255 mm). Countersinks
    for the four M5 fixing screws were evaluated and rejected: the hole centres
    sit 4.9 mm from the panel edge, while Schaeffer's DIN 74A-M5 countersink is
    Ø10.94 and even the smallest standard M5 countersunk head is Ø9.2. The
    countersink support stays in the generator behind CSK_TYPE.
    [fs1a_frontpanel_bohrungen.csv, fs1a_gehaeuse.step]
2026-09-22 Countersink the four panel fixing screws for DIN 965 M5
    A custom countersink (cone 9.2 mm, 90 deg, drill 5.3, 2.15 mm deep) replaces
    the plain hole. DIN 965 / ISO 7046 is the only standard M5 countersunk head
    that fits the 4.9 mm edge distance: 9.2 mm head leaves 0.30 mm of material,
    while DIN 7991 (10.0) and Schaeffer's DIN 74A-M5 countersink (10.94) would
    break out over the panel edge.
    [fs1a_frontpanel_bohrungen.csv, fs1a_gehaeuse.step]
2026-09-22 Revert to cheese head fixing screws
    The DIN 965 countersink works but leaves only 0.30 mm of material at the
    panel edge. Back to a plain 5.3 mm hole; the countersink stays in the
    generator behind CSK_TYPE.
    [fs1a_frontpanel_bohrungen.csv, fs1a_gehaeuse.step]
2026-09-29 Put the revision in every generated file name (Rev0.1)
    Generated files are now named FS1A_<part>_Rev<x.y>[_<suffix>].<ext>, the same
    scheme the ARP3620 boards use, so ordered panels and data files cannot drift
    apart. REV lives once at the top of fs1a_panel.py; the rear panel, enclosure and
    STEP scripts take it from there. Generator scripts and input data stay
    unversioned - they are the tool, not the deliverable.
    [FS1A_Deckel_Boden_Rev0.1.dxf, FS1A_Deckel_Boden_Rev0.1_bohrungen.csv, FS1A_Frontpanel_Rev0.1.dxf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]
2026-10-07 Rendered views of the FS-1A panel, enclosure and rear on the start page
    Three Blender renders built from the STEP assembly these scripts produce, with
    the print artwork mapped onto the panel, so the start page shows the actual
    design instead of a wireframe. fs1a_blender.py regenerates them end to end:
    FreeCAD tessellates the STEP, Chrome renders the artwork as a texture.
    Also notes that control panel PCBs for the FS-1A are available on request from
    diysynth.de; those boards stay out of this repository.
2026-10-08 Show the FS-1A control panel PCBs on the info pages
    Two Blender views of the three boards mounted behind the panel, rendered from
    the same STEP pipeline as the case images. Component side only - no copper
    layers, so the layout itself stays unpublished, as do the design files.
2026-10-08 Drop the old FreeCAD control views of the enclosure
    The Blender renders replaced them; the wireframe and the front view only
    duplicated what the new images show better.
2026-10-10 Rev0.2: power switch cutout 0.2 mm larger in both directions
    The Marquardt rocker went into the datasheet cutout (12.3 x 27.2) only with
    force, so it is now 12.5 x 27.4. Everything regenerated and renamed to Rev0.2:
    DXF, SVG, drill schedules, print PDF, STEP and the rendered views.
    The three .fpd are missing for now - they can only come from FrontDesign, and
    the machine was locked. Both READMEs say so and how to make them.
    [FS1A_Deckel_Boden_Rev0.2.dxf, FS1A_Deckel_Boden_Rev0.2_bohrungen.csv, FS1A_Frontpanel_Rev0.2.dxf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]
2026-10-10 Rev0.2: the three Schaeffer files
    Built in FrontDesign from the Rev0.2 scripts, so the panel now carries the
    larger power switch cutout.
2026-10-10 Rev0.3 of the panel set
    Same geometry as Rev0.2 - the step is about how the colour print variant is
    produced. The script no longer saves that .fpd: Print white and Underprint white
    only exist in FrontDesign's dialog, so a script-written file always had them off
    and the published Rev0.2 file was wrong in that one respect. The script now
    leaves it unsaved and says what to set and under which name to save.
    Also fixes the start page, which still pointed at the Rev0.1 renders and had
    shown broken images since the Rev0.2 rename. The control PCB images keep their
    own revision - that is the boards' stand, not the panel's.
    [FS1A_Deckel_Boden_Rev0.3.dxf, FS1A_Deckel_Boden_Rev0.3_bohrungen.csv, FS1A_Frontpanel_Rev0.3.dxf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]
2026-10-10 Rev0.3: the three Schaeffer files, print variant with white set
    The print variant now carries 'Print white' and 'Underprint white', which the
    script cannot set. Built from the Rev0.3 scripts and saved by hand under that
    name, so it is the first published print file that is actually correct.
